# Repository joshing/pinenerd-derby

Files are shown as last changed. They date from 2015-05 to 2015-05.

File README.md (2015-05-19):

# Project for an Arduino-controlled 1-lane Pinewood Derby practice track

This is just the timing and starting gate controls, you have to supply a track. I used 
BSOA practice track and a PVC frame (http://www.abc-pinewood-derby.com/track-stand.php).
I cut out a slot in the middle of the topmost track section for a starting gate, then a 7mm
square hole in the middle of the track for a finish line, through which an IR light beam
shines and signals the Arduino when a car crosses the finish (I used this IR pair 
https://www.sparkfun.com/products/241and this basic circuit: 
http://www.reconnsworld.com/ir_ultrasonic_basicirdetectemit.html)

The Arduino controls an LCD display with buttons (https://www.adafruit.com/products/714).
Pressing the SELECT button starts a race by lowering the starting gate with a servo, waiting
for the IR beam to be broken at the finish, and displaying the time between the two. The race
can be reset with the LEFT (Back) button.

## This project requires the following arduino libraries:
* https://github.com/adafruit/Adafruit-RGB-LCD-Shield-Library
* http://www.arduino.cc/en/Reference/Servo
* http://www.arduino.cc/en/reference/Wire

## 3D Files
STL and Inventor source files are included for the following physical parts:
* <b>Servo Gate</b>: Attaches to a standard size servo and controls car starting
* <b>Servo Bracket</b>: Servo mount for attaching beneath the track
* <b>Finish Line</b>: Mount for IR emitter and detector. Requires a 7mm square hole
  in the track at the finish line where the bottom is mounted under.

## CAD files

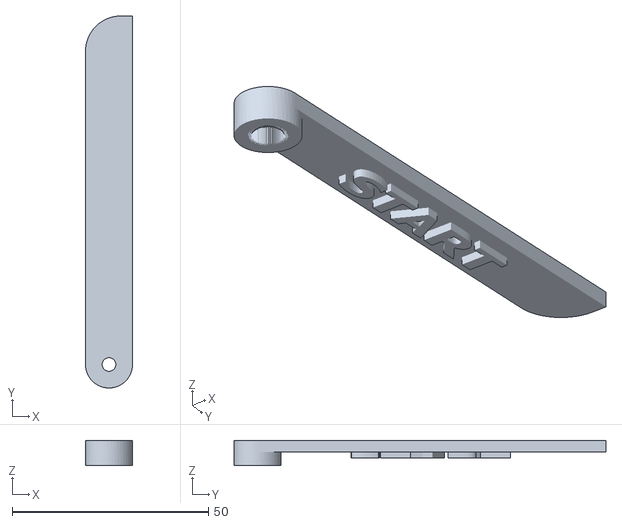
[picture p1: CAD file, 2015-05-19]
3DPrinted/STL/ServoStartArm.stl
12.0 x 94.9 x 6.50

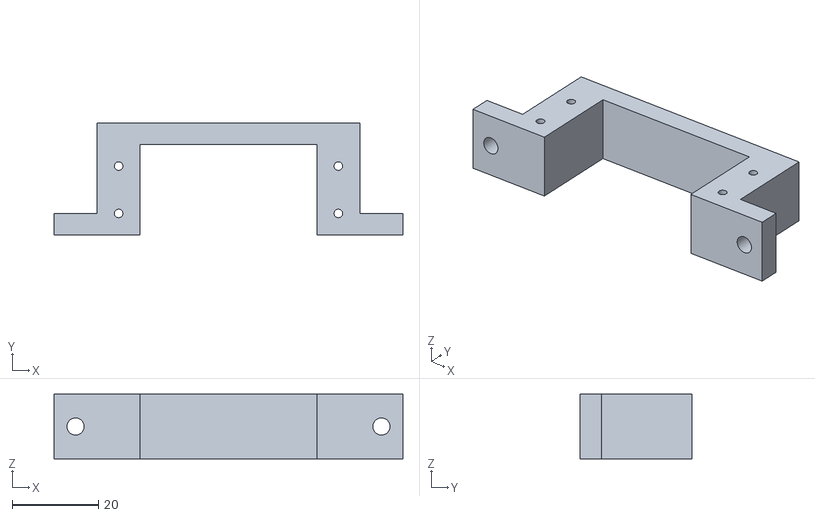
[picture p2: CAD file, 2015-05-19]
3DPrinted/STL/ServoMount.stl
81.0 x 26.0 x 15.0

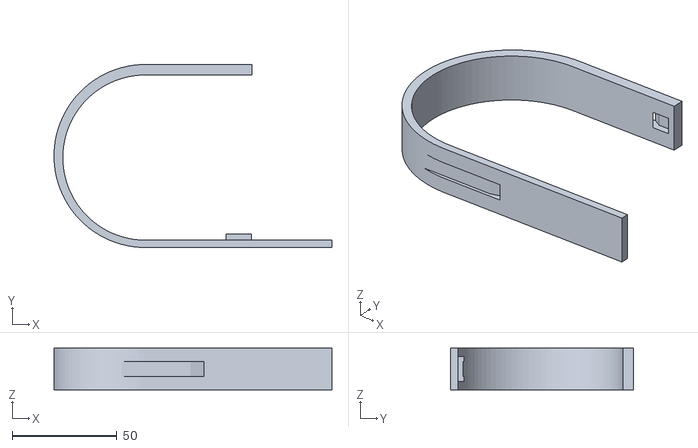
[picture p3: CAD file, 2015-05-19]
3DPrinted/STL/Finish.stl
132.5 x 87.2 x 20.0

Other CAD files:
3DPrinted/Inventor/Finish.ipt
3DPrinted/Inventor/ServoMount.ipt
3DPrinted/Inventor/ServoStartArm.ipt

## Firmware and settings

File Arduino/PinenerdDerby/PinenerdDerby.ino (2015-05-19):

/*
    Copyright (c) 2015 Josh Gunnar

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
    THE SOFTWARE IS PROVIDED "AS IS", WITHOUT WARRANTY OF ANY KIND,
    EXPRESS OR IMPLIED, INCLUDING BUT NOT LIMITED TO THE WARRANTIES
    OF MERCHANTABILITY, FITNESS FOR A PARTICULAR PURPOSE AND NONINFRINGEMENT.
    IN NO EVENT SHALL THE AUTHORS OR COPYRIGHT HOLDERS BE LIABLE FOR ANY
    CLAIM, DAMAGES OR OTHER LIABILITY, WHETHER IN AN ACTION OF CONTRACT,
    TORT OR OTHERWISE, ARISING FROM, OUT OF OR IN CONNECTION WITH THE SOFTWARE
    OR THE USE OR OTHER DEALINGS IN THE SOFTWARE.
*/
#include <Wire.h>
#include <Adafruit_MCP23017.h>
#include <Adafruit_RGBLCDShield.h>
#include <Servo.h> 
#include "HardwareConfig.h"

#define WHITE 0x7 // For the LCD
 
Servo myservo; 
Adafruit_RGBLCDShield lcd = Adafruit_RGBLCDShield();
uint8_t buttons;

void setup() 
{ 
  // Setup IR pins
  pinMode(IR_OUTPUT_PIN, OUTPUT);
  pinMode(IR_INPUT_PIN, INPUT);
  
  // Setup servo acting as the starting gate
  myservo.attach(SERVO_PIN);
  myservo.write(0);
  delay(2000); // Can't call detach() before movement is finished
  myservo.detach(); // If left attached, the servo will 'twitch'
  
  // Setup the LCD
  lcd.begin(16, 2);
  lcd.setBacklight(WHITE);
  lcd.clear();
  lcd.setCursor(0, 0);
  lcd.print("READY");
} 
 
void loop() { 
  // Basically, just wait for a race to start, signaled by the 'select' button
  buttons = lcd.readButtons();
  if (buttons) {
    if (buttons & BUTTON_SELECT) {
      race();
    }
  }
} 

void race() { 
  // Error flag
  boolean error = false;
  
  // Update display
  lcd.clear();
  lcd.setCursor(0, 0);
  lcd.print("Race!");
  
  // Turn on the IR beam
  digitalWrite(IR_OUTPUT_PIN, HIGH);
  
  // Lower the gate
  myservo.attach(SERVO_PIN);
  myservo.write(GO_SERVO_POSITION);
  
  // Note the start time
  long start = millis();
  
  // Wait until the IR beam at the finish is broken
  while (analogRead(IR_INPUT_PIN) < IR_ANALOG_THRESHOLD) {
    // It's possible that the IR beam fails to register the finish..
    // so provide an out by checking for the left (back) button
    buttons = lcd.readButtons();
    if (buttons) {
      if (buttons & BUTTON_LEFT) {
        error = true;
        break;
      }
    }
  }
  
  if (!error) {
    // Figure out elapsed time in seconds
    long time = millis() - start;
    float timeSeconds = (float)time/1000;
    
    // Show the result
    lcd.clear();
    lcd.setCursor(0,0);
    lcd.print("Time: ");
    lcd.print(timeSeconds, 3);
    lcd.print("s");
  }
  else {
    lcd.clear();
    lcd.setCursor(0,0);
    lcd.print("Ready");
  }
  
  // Clean up, set the starting gate back up and turn off
  //  the IR beam
  myservo.write(STOP_SERVO_POSITION);
  delay(2000); // Can't detach until the movement is finished
  myservo.detach();
  digitalWrite(IR_OUTPUT_PIN, LOW);
}

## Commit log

2015-05-19 Adding 3D parts
    [PinewoodFinish.ipt, PinewoodFinish.stl, PinewoodServoMount.ipt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]
2015-05-19 Fixing name consistency issues
    [Finish.ipt, Finish.stl, ServoMount.ipt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]
